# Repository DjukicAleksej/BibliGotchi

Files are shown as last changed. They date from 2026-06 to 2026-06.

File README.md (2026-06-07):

<div align="center">

# 🎮 BibliGotchi

<p align="center" style="font-size: 1.1em; max-width: 800px; line-height: 1.6;">
  A custom-made Tamagotchi with a heavenly touch. Made by a 17-year-old from Bosnia and Herzegovina, this project showcases my learning journey in the hardware ecosystem. I designed this using KiCad for the PCB, OnShape for the structural case, and the Arduino IDE for the firmware.
</p>

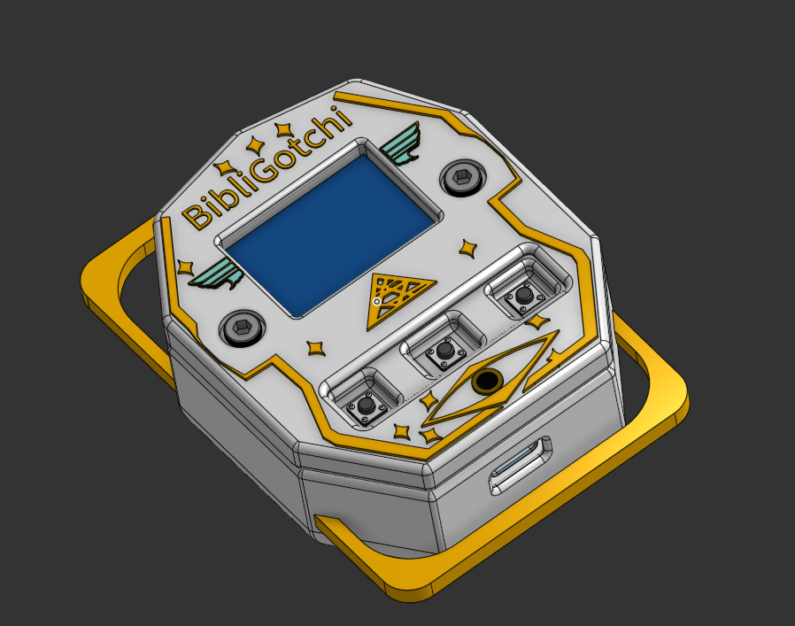
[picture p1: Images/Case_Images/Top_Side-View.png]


<p align="center" style="max-width: 800px; line-height: 1.6;">
  This Tamagotchi features 3 main tracking stats: <strong>Hunger</strong>, <strong>Energy</strong>, and <strong>Happiness</strong>. You can improve these parameters by physically interacting with the device using tactile buttons—each mapped to mapped behaviors like playing, feeding, or sleeping. Depending on active stats, 4 distinct screen expressions dynamically cycle: neutral, happy, sad, or sleeping. All 32x32 pixel sprites are custom-drawn, giving you the template to easily drop in your own custom artwork!
</p>

## 💡 Why Did I Build This?

<p align="center" style="max-width: 800px; line-height: 1.6;">
  I built this project to qualify for <strong>Fallout</strong>, a hardware hackathon organized by the non-profit community <strong>Hack Club</strong>. I gravitated toward building a Tamagotchi because it sits at the perfect crossroads: complex enough to challenge my design skills, yet interactive enough to stand out. In a world saturated with purely web-based apps, having a tangible, physical device makes it uniquely engaging. Through this process, I significantly deepened my understanding of firmware architecture and structural enclosure engineering.
</p>

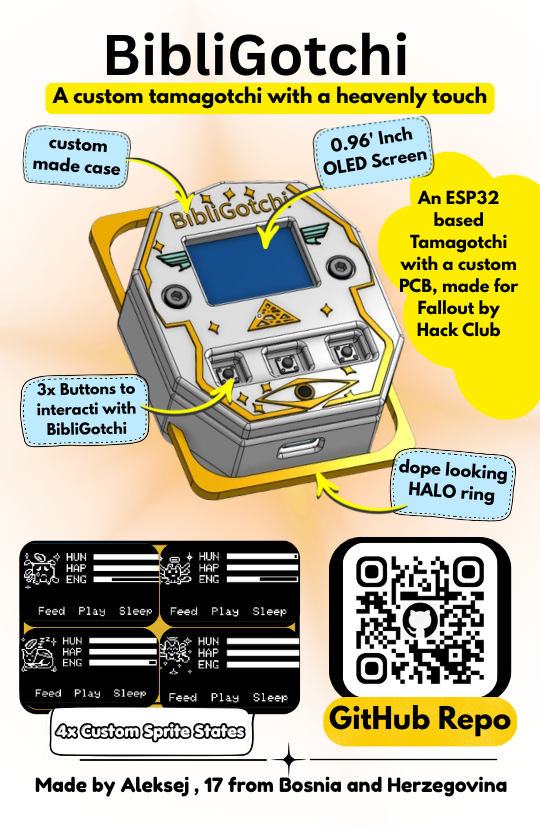
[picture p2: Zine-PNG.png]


---

<p align="center">
  <a href="Zine.pdf">📖 Read the Zine</a>
  &nbsp;&nbsp;•&nbsp;&nbsp;
  <a href="PCB-Files/Gerbers.zip">📦 Download Gerbers</a>
  &nbsp;&nbsp;•&nbsp;&nbsp;
  <a href="Case-Files/">📐 STEP Case Files</a>
  &nbsp;&nbsp;•&nbsp;&nbsp;
  <a href="BOM/BOM.csv">🧾 PCB BOM</a>
</p>

---

</div>

## 🔍 Overview
BibliGotchi is built around the **Seeed Studio XIAO ESP32-C3**, utilizing a custom PCB routed in KiCad to interface all peripherals smoothly. 

### Key Features:
* **Display**: 0.96" OLED screen for crisp UI rendering.
* **Power**: Integrated 3.7V 500mAh lithium-polymer battery.
* **Audio & Input**: Passive buzzer for alerts alongside 3 interactive navigation switches.
* **Enclosure**: Modeled inside OnShape ([View OnShape CAD Here](https://cad.onshape.com/documents/44d918d4bf107306610f1545/w/f7f086a823beff1369bb4e84/e/70df229ea8fe1c8cd39e3565)). Features filleted edge-geometry to completely eliminate sharp surfaces, precise cutouts for the USB-C port, and an internal structural sub-enclosure. The battery is safely clamped using a dual-screw retention bracket.
* **Firmware**: Written in C++ targeting the Arduino runtime environment. It implements real-time lifecycle status loops (tracking age, happiness levels, and depletion intervals) rendered via custom graphical progress bars.

---

## 📐 Case Gallery

| Top View | Top Side View |
| :---: | :---: |
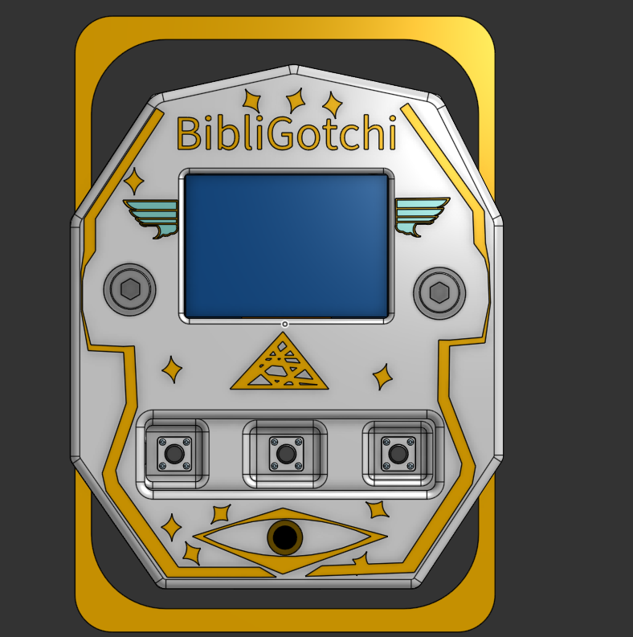
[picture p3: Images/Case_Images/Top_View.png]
Normal case view
|  | Top side-view |
| **Bottom View** | **Exploded View** |
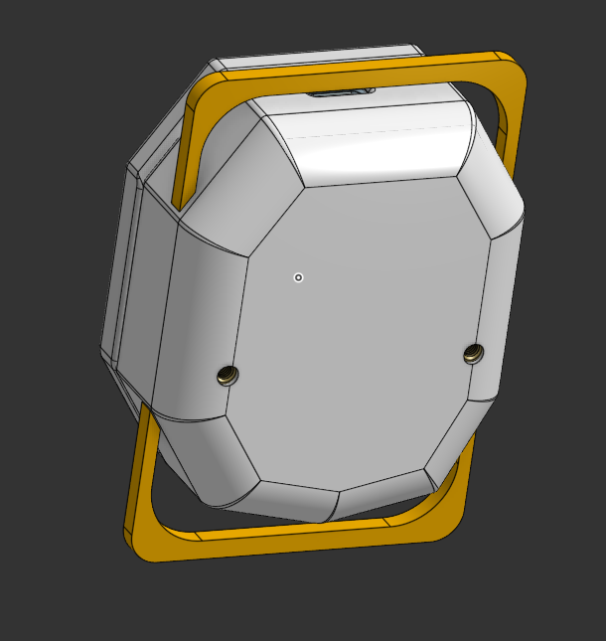
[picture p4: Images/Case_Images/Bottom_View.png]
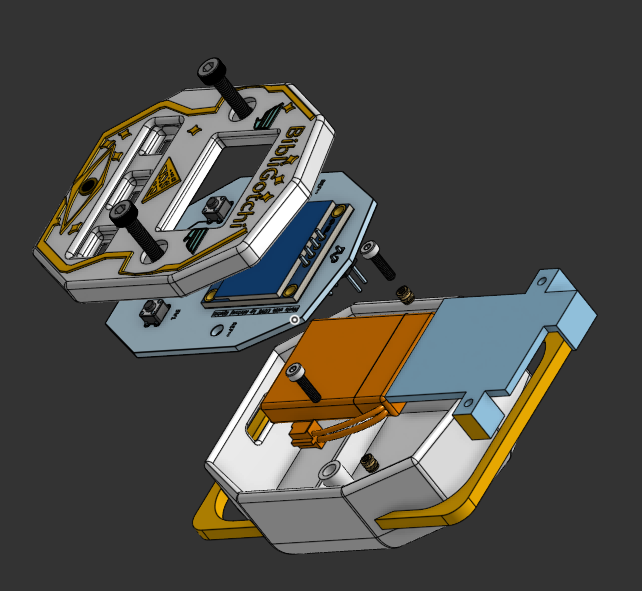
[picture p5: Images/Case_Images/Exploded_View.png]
|  |  |

---

## ⚡ PCB Gallery

| Top View 1 | Top View 2 |
| :---: | :---: |
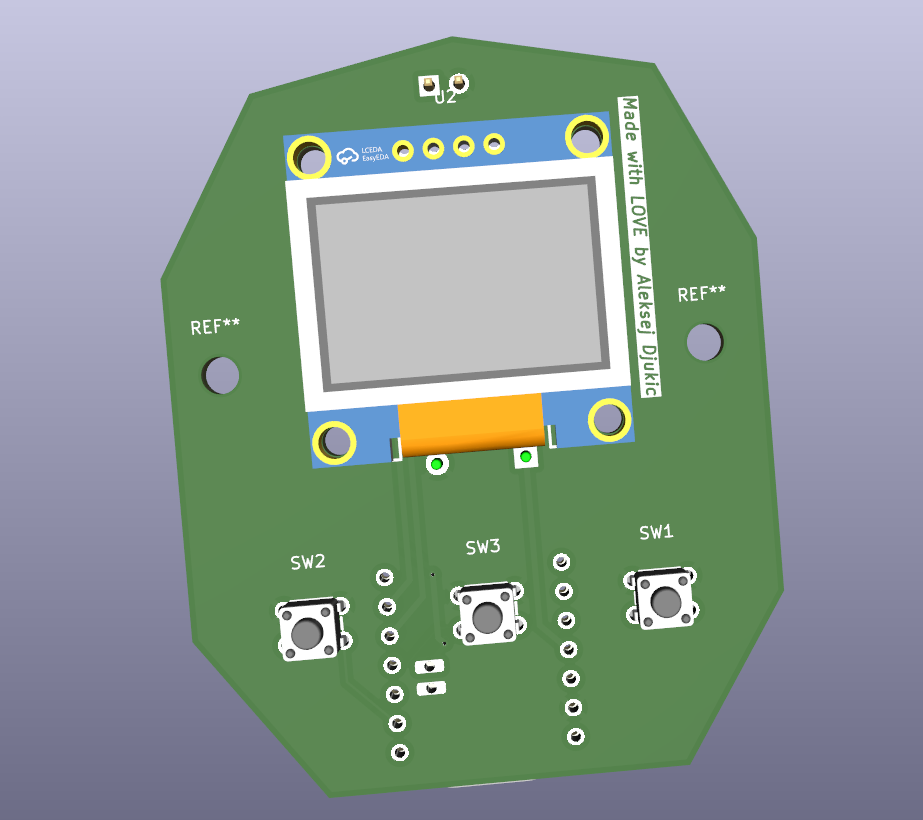
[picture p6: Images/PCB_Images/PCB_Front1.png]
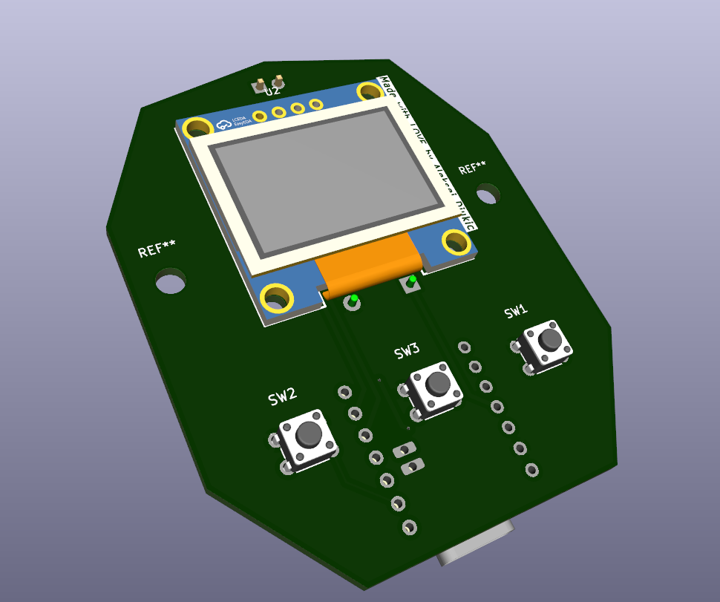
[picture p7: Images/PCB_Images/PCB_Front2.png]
|  |  |
| **Bottom View 1** | **Bottom View 2** |
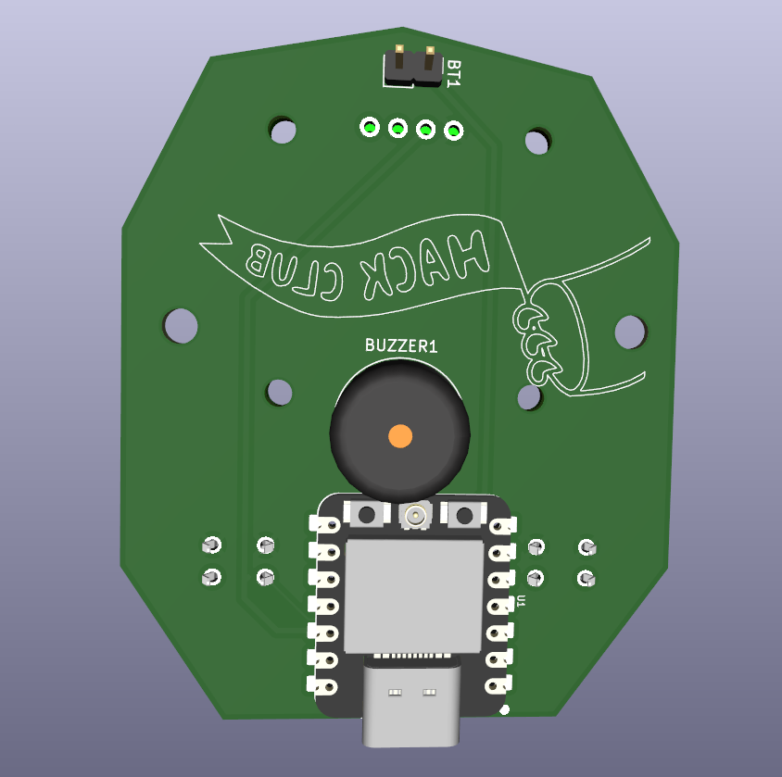
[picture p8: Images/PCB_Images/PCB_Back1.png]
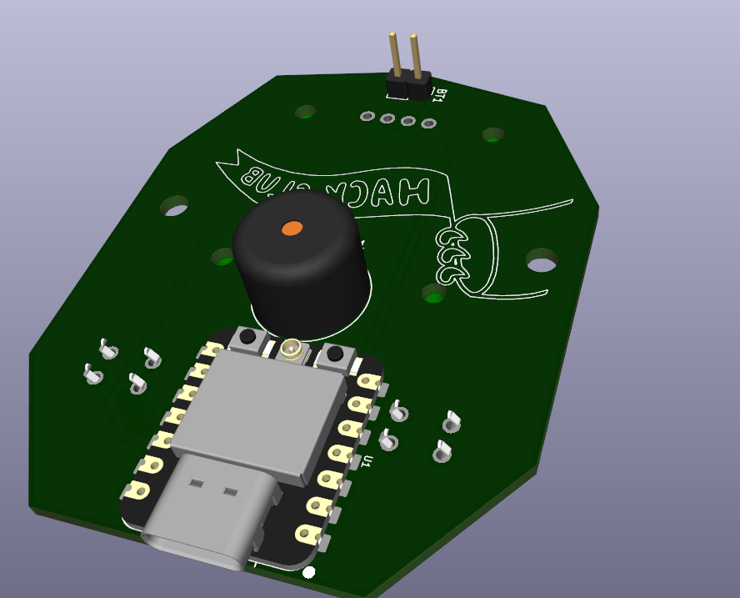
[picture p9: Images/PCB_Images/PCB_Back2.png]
|  |  |

### Schematic

<p align="center">
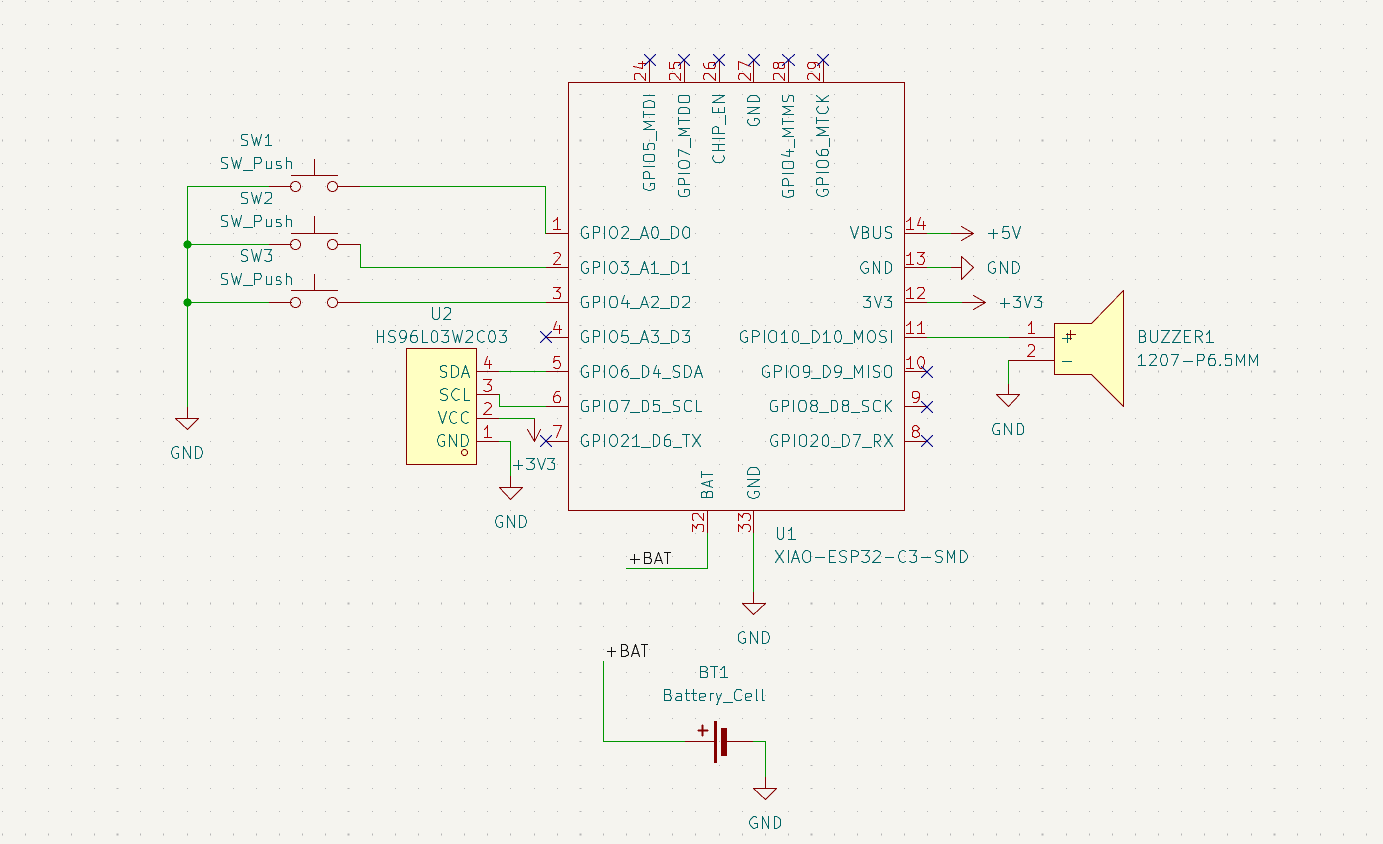
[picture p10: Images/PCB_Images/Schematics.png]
USB hub schematic
  
</p>
---

## 🗺️ Trace Routing

| Top Routing Layer | Bottom Routing Layer |
| :---: | :---: |
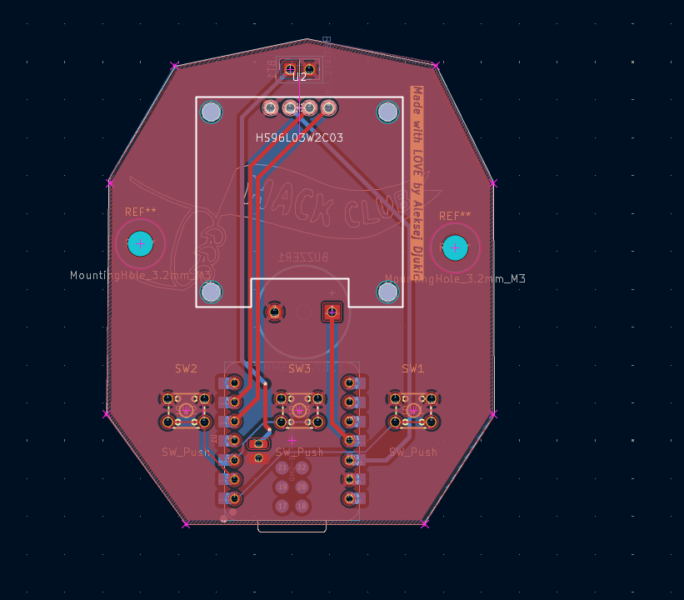
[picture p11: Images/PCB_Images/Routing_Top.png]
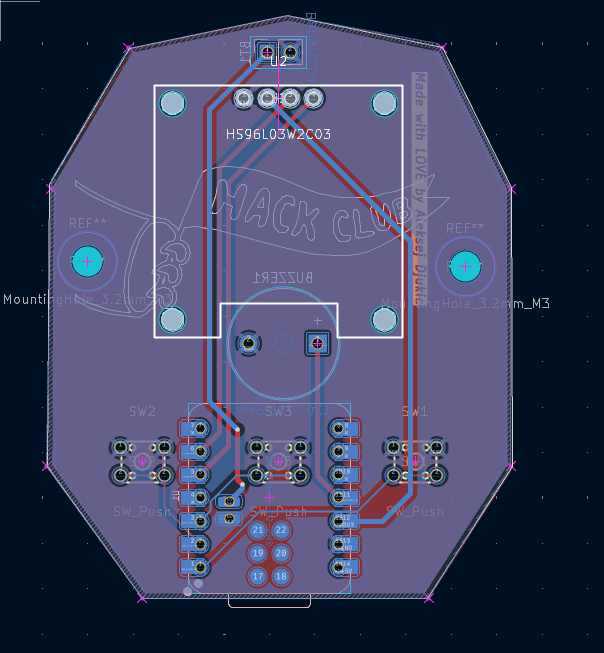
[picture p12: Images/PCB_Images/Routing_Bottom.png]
|  |  |

---

### 🛠️ Bill of Materials (BOM)

| Item | Description | Value | LCSC Part | Qty | MOQ | Unit Price | Total Price | Resources |
| :--- | :--- | :--- | :--- | :---: | :---: | :---: | :---: | :--- |
| Battery | Single-cell battery | Battery_Cell | | 1 | 1 | $5.11 | $5.11 | [Datasheet](https://www.kiwi-electronics.com/image/catalog/pdf/LP503035%20500mAh%203.7V%20%28AD306053%29%2020230615%5B34%5D.pdf), [Purchase Link](https://www.aliexpress.com/item/1005006043243361.html) |
| Buzzer | Passive Buzzer | 1207-P6.5MM | C49246964 | 1 | 10 | $0.03 | $0.32 | [Datasheet](https://www.lcsc.com/datasheet/C49246964.pdf), [Purchase Link](https://www.lcsc.com/product-detail/C49246964.html) |
| Switch | Push button switch, generic, two pins | SW_Push | C2888493 | 3 | 50 | $0.01 | $0.54 | [Datasheet](https://www.lcsc.com/datasheet/C2888493.pdf), [Purchase Link](https://www.lcsc.com/product-detail/C2888493.html) |
| ESP32-C3 MCU | IoT mini development board | XIAO-ESP32-C3-SMD | | 1 | 1 | $5.67 | $5.67 | [Datasheet](https://files.seeedstudio.com/wiki/XIAO_WiFi/Resources/esp32-c3_datasheet.pdf), [Purchase Link](https://www.aliexpress.com/item/1005006979844970.html) |
| OLED Display | 0.96" Inch OLED Display | HS96L03W2C03 | C5248080 | 1 | 1 | $2.24 | $2.24 | [Datasheet](https://www.lcsc.com/datasheet/C5248080.pdf), [Purchase Link](https://www.lcsc.com/product-detail/C5248080.html) |
| PCB | Hardware Fabrication Support | - | - | 1 | 5 | - | $4.00 | - |
| PCB Shipping | Shipping for the PCB, its kinda expensive cause I live outside the EU | - | - | - | - | - | $26.00 | - |
| **Total** | | | | **8** | **68** | **$13.10** | **$43.88** | |

### ⚙️ Structural Fasteners (Build BOM)

| Item | Description | Quantity | Total Price |
| :--- | :--- | :---: | :--- |
| M3 L20 Screws | Connects the structural Bottom and Top case layers while mounting the internal PCB safely | 2 | $0.10 
| M2 Screws L8mm | Shorter structural screws allocated to tighten down the custom internal battery clamp | 2 | $0.10 
| M3 Heat Set Inserts | Threaded brass inserts allowing permanent, secure fastening profiles for outer casing | 2 | $0.10 
| M2 Heat Set Inserts | High-precision brass inserts matching structural point stabilization requirements | 2 | $0.20 
| **Total** | | **12** | **$0.60** |

---

## 🔧 Case Assembly Tutorial

### Step 1: Putting in the Battery
Seat the Battery into its enclosure in the Bottom Part, then put heat set inserts into the Battery Holder and place it onto the Battery Enclosure and screw it in.

| Align the Battery | Secure it with the Battery Holder |
| :---: | :---: |
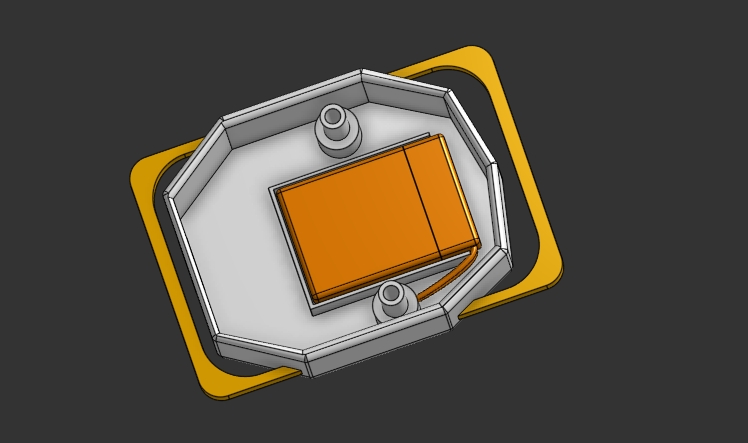
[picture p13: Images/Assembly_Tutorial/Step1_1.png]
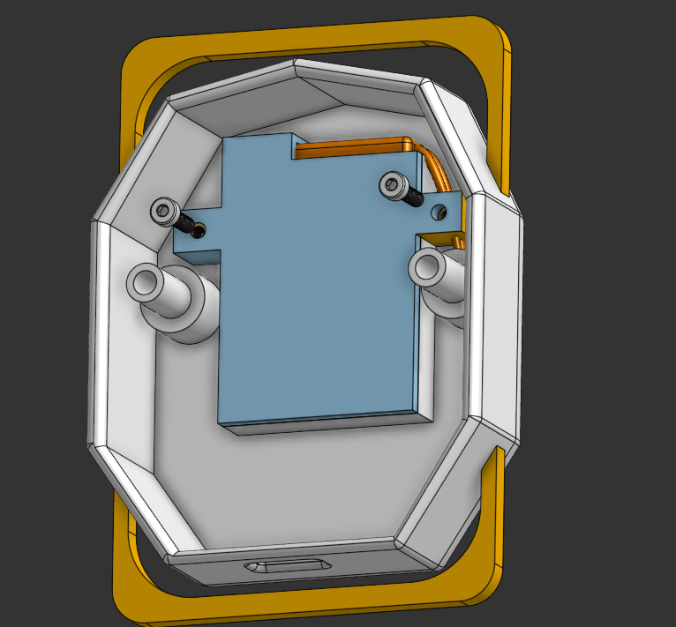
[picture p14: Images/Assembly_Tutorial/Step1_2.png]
|  |  |

### Step 2: Assembling the PCB and the Top Cover to the Bottom Part
Press-fit the M3 brass heat-set inserts straight into the designated holes inside the lower structural wall. Bring the PCB to align its mounting holes with the supports from the Bottom Part, and then Align the Top Cover so that you can screw in the top cover and bottom cover through the hole nicely,  and drive the M3 L20 screws downward to securely clamp the whole sandwich layer together.

| Put in the M3 heat set inserts | Align the PCB | Put the Top Cover Nicely aligned on the PCB |
| :--: | :---: | :---: |
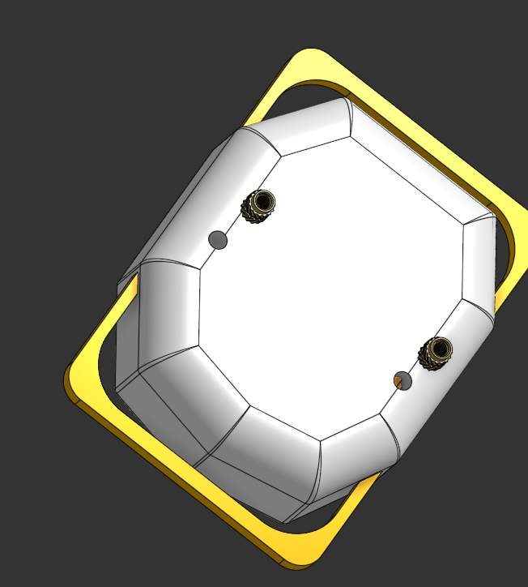
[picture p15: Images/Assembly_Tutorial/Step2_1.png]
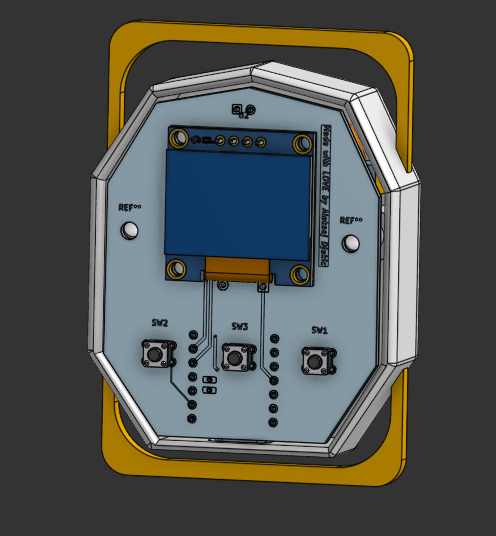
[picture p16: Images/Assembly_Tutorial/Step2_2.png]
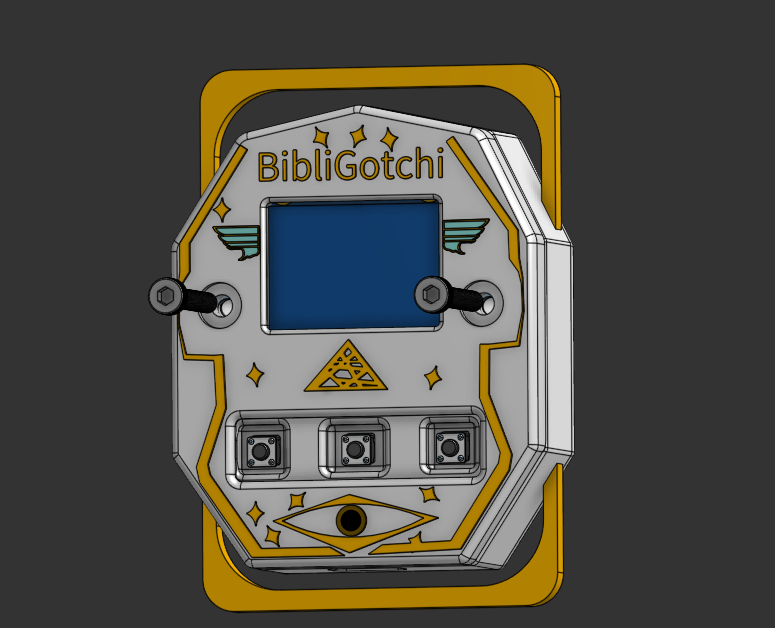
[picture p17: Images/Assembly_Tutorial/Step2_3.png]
|  |  |   |

---

## 💻 Firmware Setup

The runtime firmware is engineered inside the Arduino core using C++. It executes cyclic ticks tracking core stat logic while parsing interactive structural button state triggers via hardware pull-up inputs:
* **Left Button (`Feed`)**: Replenishes missing core **HUN (Hunger)** values, keeping your pet fed.
* **Middle Button (`Play`)**: Trades **-5 ENG (Energy)** to buy **+10 HAP (Happiness)** metrics.
* **Right Button (`Sleep`)**: Switches state vectors directly into the deep sleeping routine, generating a custom visual screen profile and recharging **+15 ENG (Energy)** metrics.

### Expressive Character Matrix

| Sad State (`Any Stat < 30`) | Happy State (`All Stats > 50`) |
| :---: | :---: |
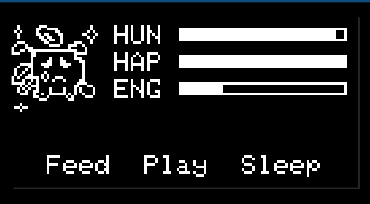
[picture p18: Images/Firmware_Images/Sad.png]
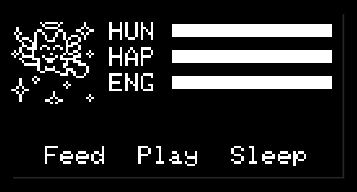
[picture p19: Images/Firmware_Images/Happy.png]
|  |  |
| **Neutral State (`Standard Default`)** | **Sleep State (`Sleep Trigger Engaged`)** |
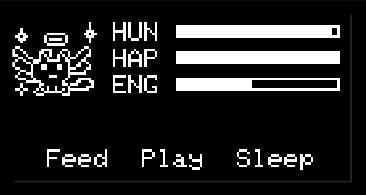
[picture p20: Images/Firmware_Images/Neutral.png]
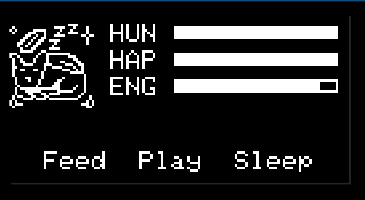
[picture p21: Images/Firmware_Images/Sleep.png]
|  |  |

---

### 🚀 Compilation & Flashing Instructions

### Step 1: Install the ESP32 Board Package URL
Because ESP32 variants require platform abstraction extensions, add the official Espressif core indexes inside your environment parameters:
1. Open the **Arduino IDE**.
2. Navigate to **File** > **Preferences** (macOS: **Arduino IDE** > **Settings**).
3. Append the following address into the **Additional Boards Manager URLs** input row:
   `https://espressif.github.io/arduino-esp32/package_esp32_index.json`
   *(Note: Separate multiple indices using standard commas if you have existing entries).*
4. Click **OK** and allow indexing to finalize.

### Step 2: Fetch the Core Toolkit
1. Enter the Board Repository panel via **Tools** > **Board** > **Boards Manager**.
2. Run an evaluation sweep searching for `esp32`.
3. Locate **esp32 by Espressif Systems** and click **Install**. 
   *(Important: Verify package versions display `3.0.0` or newer to guarantee complete ESP32-C3 controller support).*

### Step 3: Instantiate local Sketch Files
Create a fresh runtime workspace profile inside the environment via **File** > **New Sketch**. Save this locally on your machine.

### Step 4: Bind Target Hardware Options
1. Go to **Tools** > **Board** > **esp32**.
2. Choose your precise module footprint: **XIAO ESP32C3**.
3. Select your system hardware serial mount path line entry under **Tools** > **Port**.

### Step 5: Resolve Peripheral Libraries
Enter the library workspace panel through **Sketch** > **Include Library** > **Manage Libraries** and search for and fetch the following dependencies:
1. **Adafruit SSD1306** (by Adafruit)
2. **Adafruit GFX Library** (by Adafruit—accept any cascading tracking dependencies if prompted)

### Step 6: Deploy Flash Assets
Link your BibliGotchi assembly to your development machine using a dependable data-rated USB-C cord. Copy the logic content found within your local `BibliGotchi_Firmware.ino` file directly over to your primary IDE sketch pane.
1. Click the **Verify** icon (the top-left checkmark layout symbol) to check for structural code errors.
2. Hit the **Upload** arrow icon situated immediately alongside it to build and flash the image over onto the controller.

### Step 7: Enjoy! 🎉
With both structural chassis parameters and software components fully synchronized, your interactive BibliGotchi buddy is officially up and running!

---

<div align="center">

Built with ❤️ by Aleksej Djukic

**BibliGotchi • Fallout 2026**

</div>

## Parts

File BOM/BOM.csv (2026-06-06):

Item | Description | Value | Datasheet | LCSC Part | Link | Qty | MOQ | Unit Price | Total Price
Battery | Single-cell battery | Battery_Cell | https://www.kiwi-electronics.com/image/catalog/pdf/LP503035%20500mAh%203.7V%20%28AD306053%29%2020230615%5B34%5D.pdf | - | https://www.aliexpress.com/item/1005006043243361.html | 1 | 1 | $5.11 | $5.11
Buzzer | Passive Buzzer | 1207-P6.5MM | https://www.lcsc.com/datasheet/C49246964.pdf | C49246964 | https://www.lcsc.com/product-detail/C49246964.html | 1 | 10 | $0.03 | $0.32
Switch | Push button switch, generic, two pins | SW_Push | https://www.lcsc.com/datasheet/C2888493.pdf | C2888493 | https://www.lcsc.com/product-detail/C2888493.html | 3 | 50 | $0.01 | $0.54
ESP32-C3 MCU | IoT mini development board | XIAO-ESP32-C3-SMD | https://files.seeedstudio.com/wiki/XIAO_WiFi/Resources/esp32-c3_datasheet.pdf | - | https://www.aliexpress.com/item/1005006979844970.html | 1 | 1 | $5.67 | $5.67
OLED Display | 0.96 Inch OLED Display | HS96L03W2C03 | https://www.lcsc.com/datasheet/C5248080.pdf | C5248080 | https://www.lcsc.com/product-detail/C5248080.html | 1 | 1 | $2.24 | $2.24
PCB | PCB fabrication using JLCPCB | - | - | - | - | 1 | 5 | - | $4.00
PCB Shipping | Shipping to a country outside EU so it's expensive | - | - | - | - | 1 | 1 | - | $26.00
Total | - | - | - | - | - | 8 | 68 | $13.10 | $43.88

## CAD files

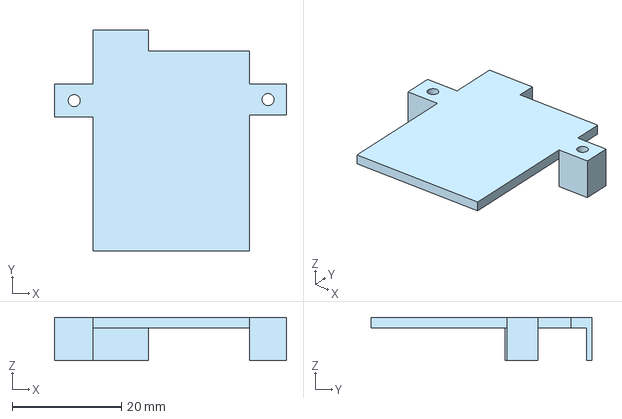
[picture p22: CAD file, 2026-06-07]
Case-Files/BibliGotchi Case - Battery Holder.step
42.4 x 40.3 x 7.92 mm

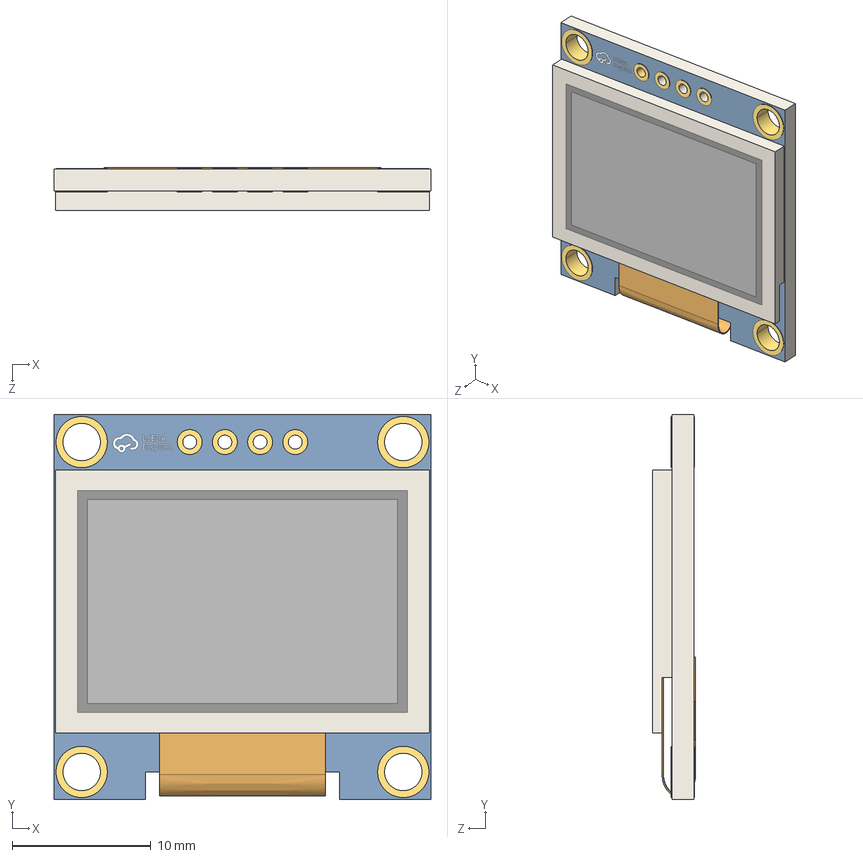
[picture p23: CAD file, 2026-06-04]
PCB-Files/Extra Imports/3D_Model_Imports/OLED-TH_L27.8-W27.2-P2.54_C9900033791.step
27.2 x 27.8 x 3.12 mm

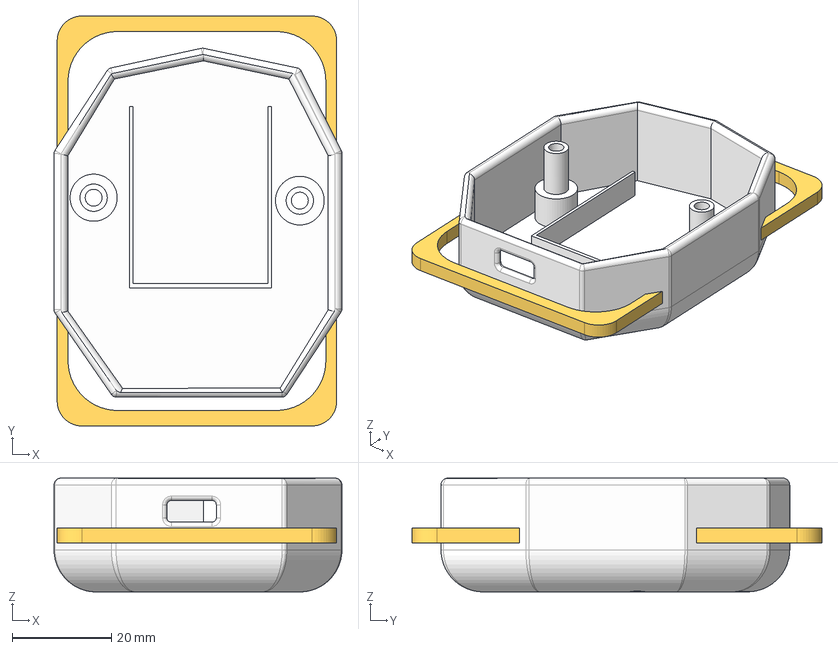
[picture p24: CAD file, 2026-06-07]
Case-Files/BibliGotchi Case - Bottom Case.step
57.9 x 82.5 x 22.9 mm

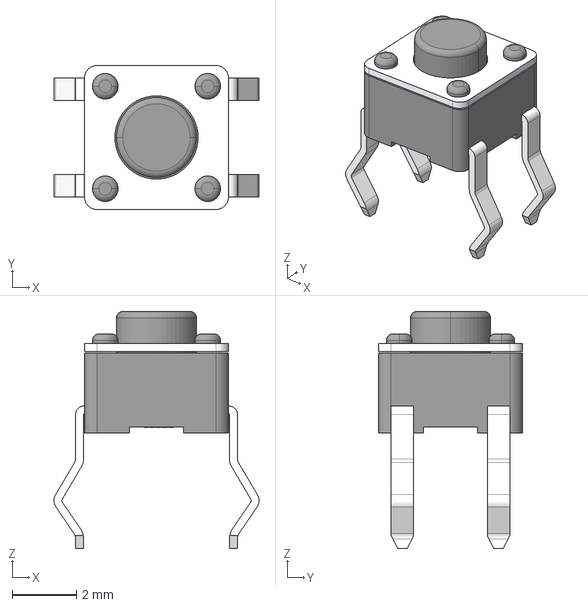
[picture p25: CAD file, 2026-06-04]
PCB-Files/Extra Imports/3D_Model_Imports/SW-TH_4P-L4.5-W4.5-P3.00-LS4.8.step
6.40 x 4.50 x 7.40 mm

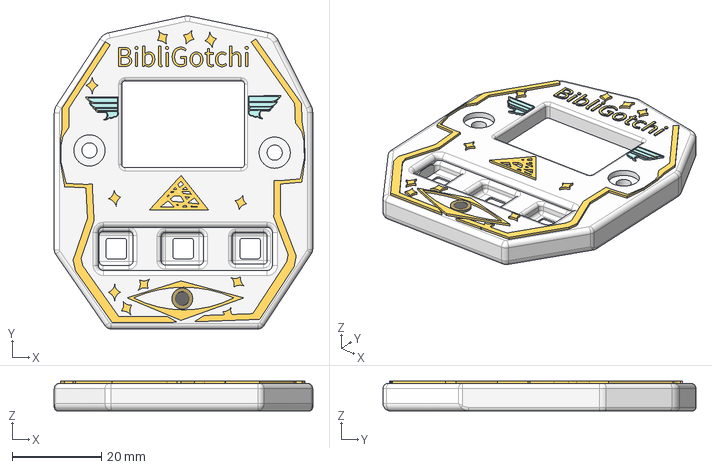
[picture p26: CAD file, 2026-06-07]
Case-Files/BibliGotchi Case - Top Cover.step
57.9 x 70.1 x 6.70 mm

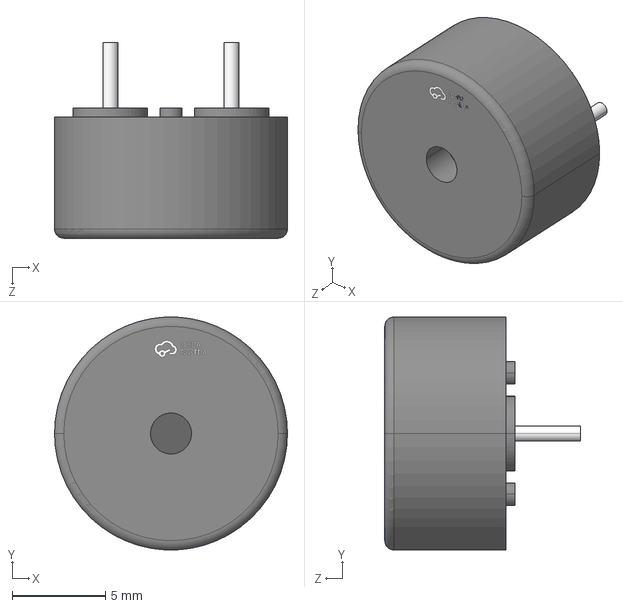
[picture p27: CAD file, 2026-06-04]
PCB-Files/Extra Imports/3D_Model_Imports/BUZ-TH_BD12.5-H7.0-P6.5.step
12.5 x 12.5 x 10.5 mm

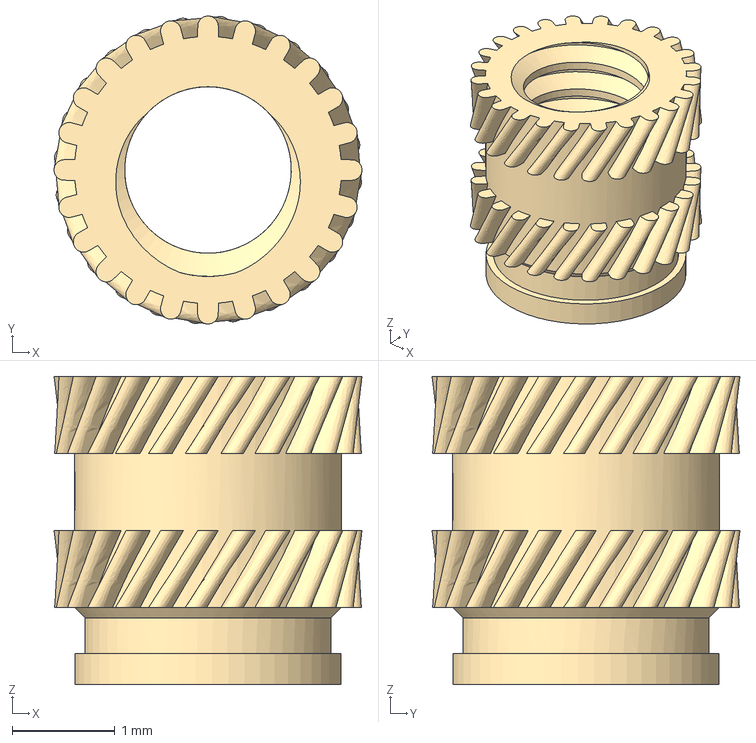
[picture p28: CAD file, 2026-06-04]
Case-Files/Components-and-Screws-3D-Models/Heat Set M2 Insert.step
3.00 x 3.00 x 3.00 mm

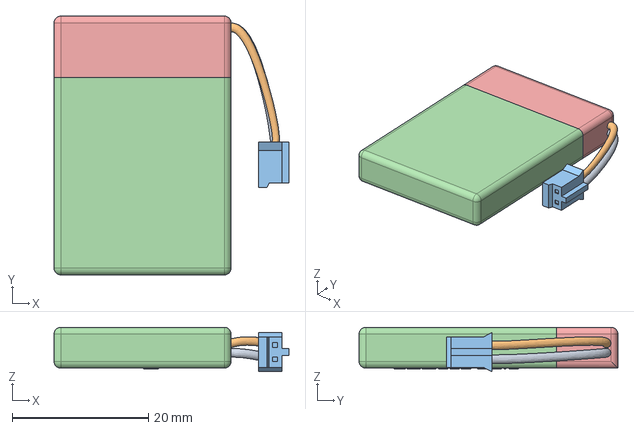
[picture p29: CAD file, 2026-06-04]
Case-Files/Components-and-Screws-3D-Models/Battery.step
34.5 x 38.0 x 6.52 mm

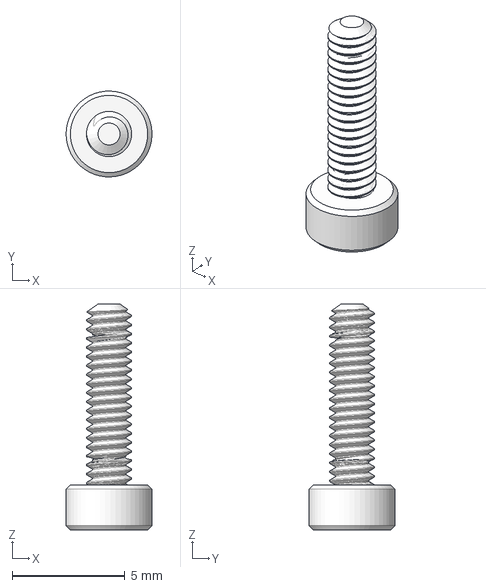
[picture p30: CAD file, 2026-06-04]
Case-Files/Components-and-Screws-3D-Models/M2_L8_Screw.step
3.80 x 3.80 x 10.00 mm

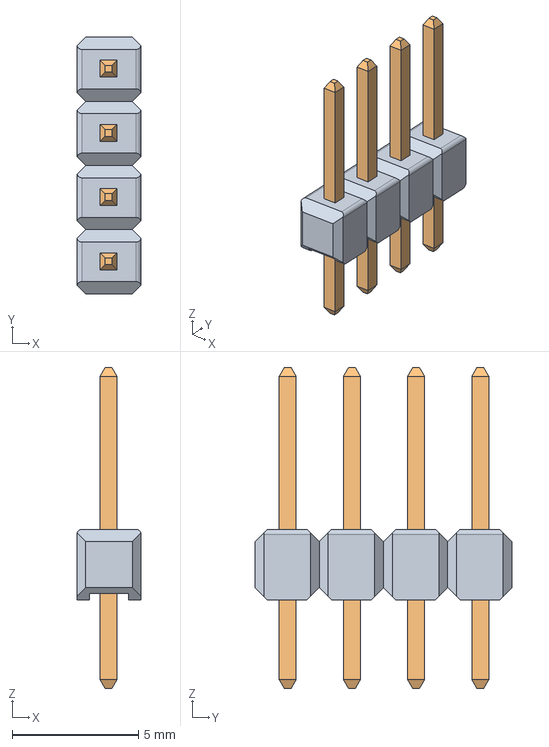
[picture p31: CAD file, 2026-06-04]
Case-Files/Components-and-Screws-3D-Models/1x4 TH Pitch 2_54mm.step
2.54 x 10.2 x 12.7 mm

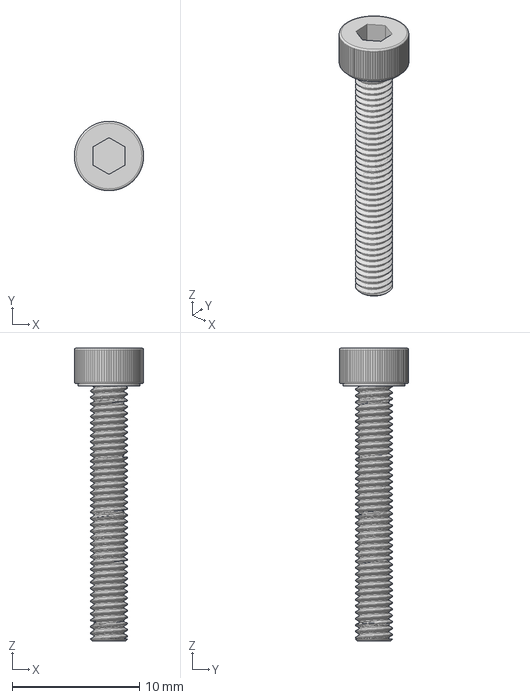
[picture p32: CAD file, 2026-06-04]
Case-Files/Components-and-Screws-3D-Models/M3_L20_Screw.step
5.45 x 5.45 x 23.0 mm

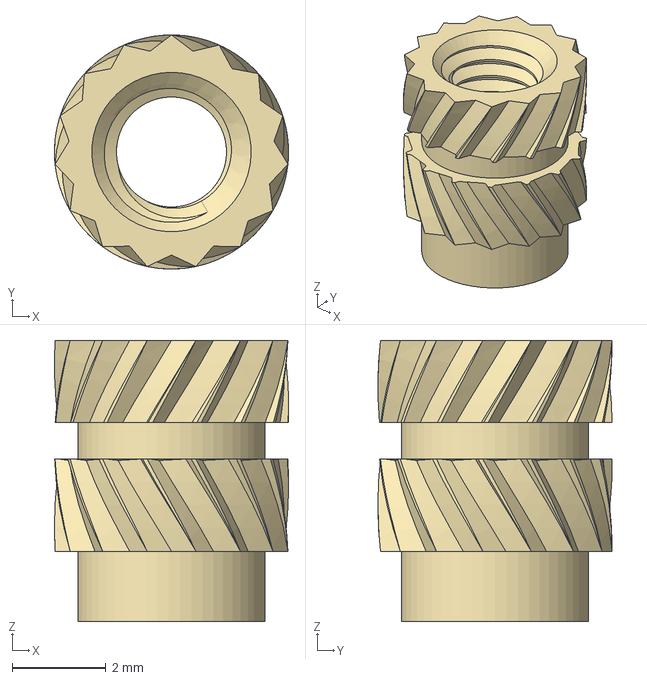
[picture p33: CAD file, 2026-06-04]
Case-Files/Components-and-Screws-3D-Models/Heat Set M3 Insert.step
5.00 x 5.00 x 6.00 mm

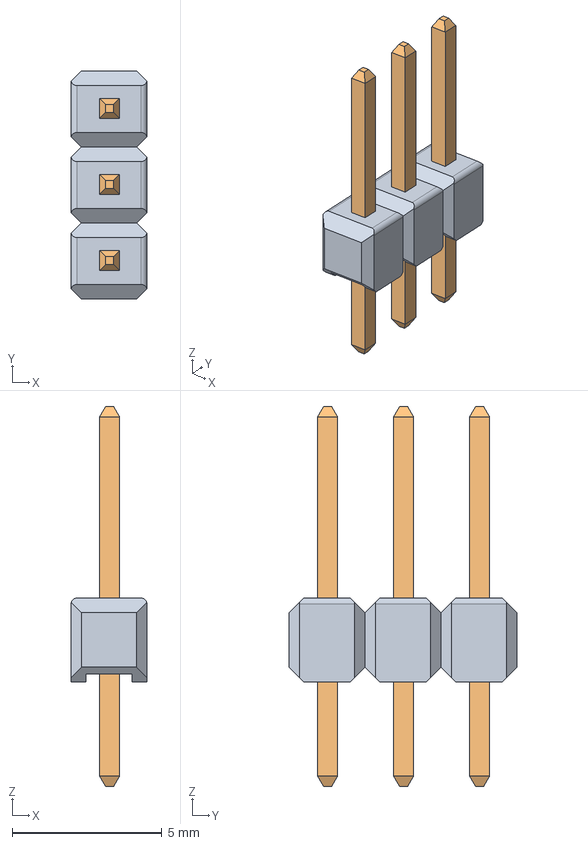
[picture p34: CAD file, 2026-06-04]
Case-Files/Components-and-Screws-3D-Models/1x3_TH Pitch 2_54mm.step
2.54 x 7.62 x 12.7 mm

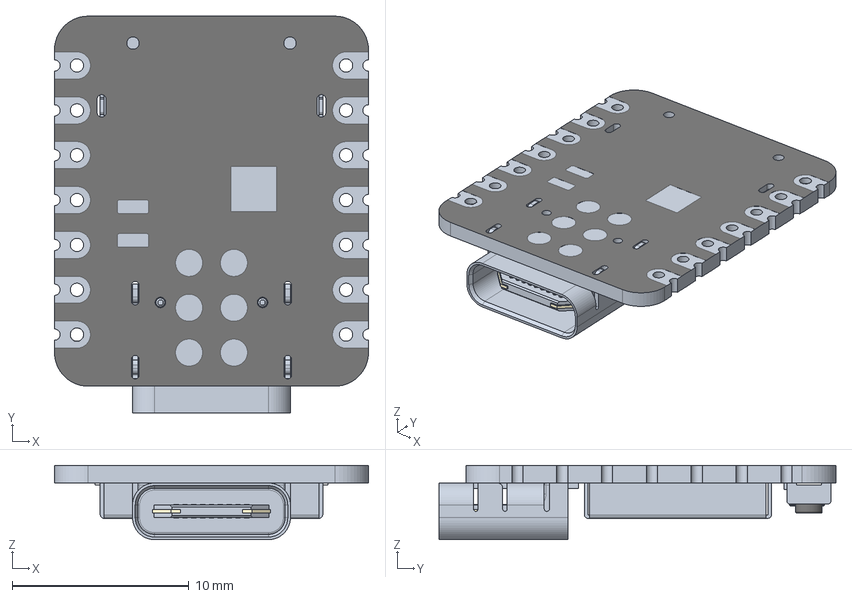
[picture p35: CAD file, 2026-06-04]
Case-Files/Components-and-Screws-3D-Models/XIAO-ESP32-C3.step
17.8 x 22.5 x 4.21 mm

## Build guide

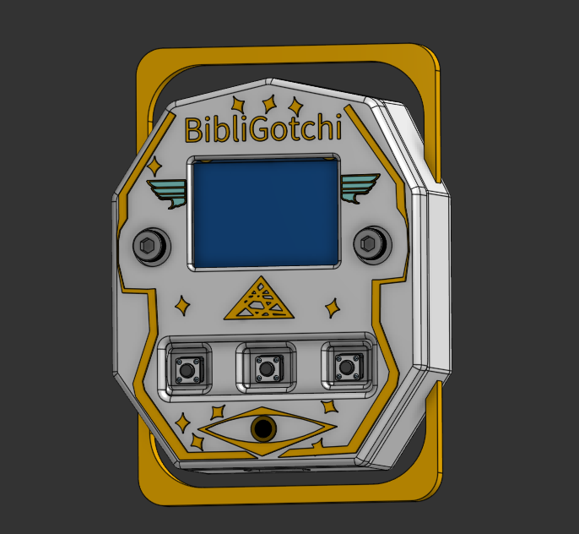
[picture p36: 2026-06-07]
Images/Assembly_Tutorial/Finished.png

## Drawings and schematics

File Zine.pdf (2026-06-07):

# BibliGotchi

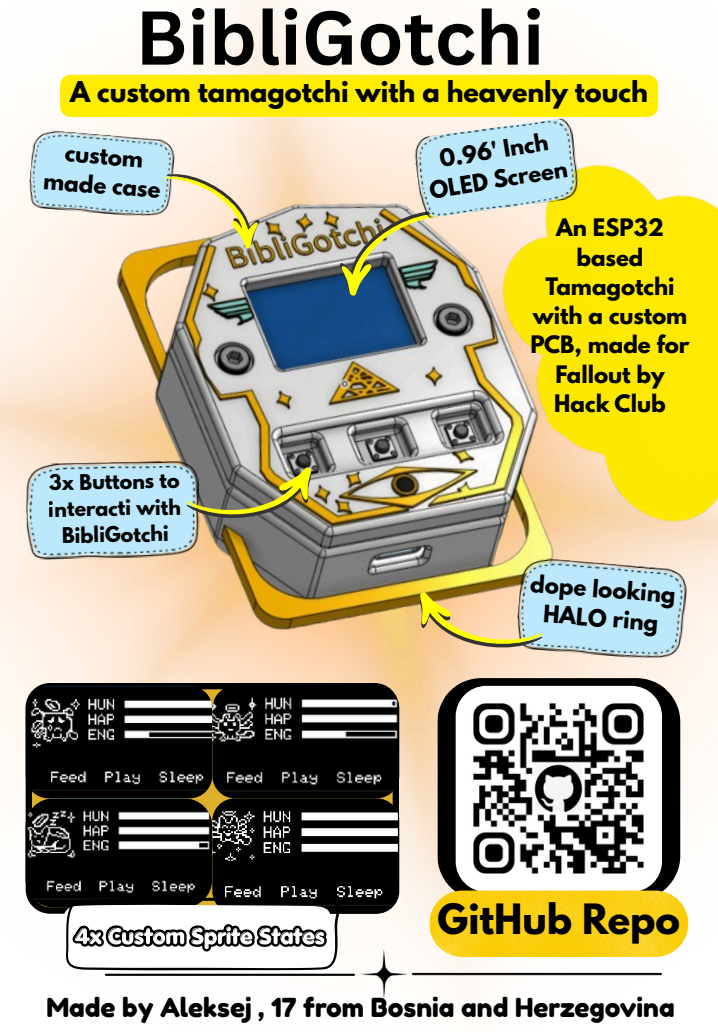
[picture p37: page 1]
3x Buttons to interacti with BibliGotchi; dope looking HALO ring; 44xx CCuussttoomm SSpprriittee SSttaatteess; GitHub Repo; custom made case; 0.96' Inch OLED Screen

A custom tamagotchi with a heavenly touch

An ESP32
based
Tamagotchi
with a custom
PCB, made for
Fallout by
Hack Club

Made by Aleksej , 17 from Bosnia and Herzegovina

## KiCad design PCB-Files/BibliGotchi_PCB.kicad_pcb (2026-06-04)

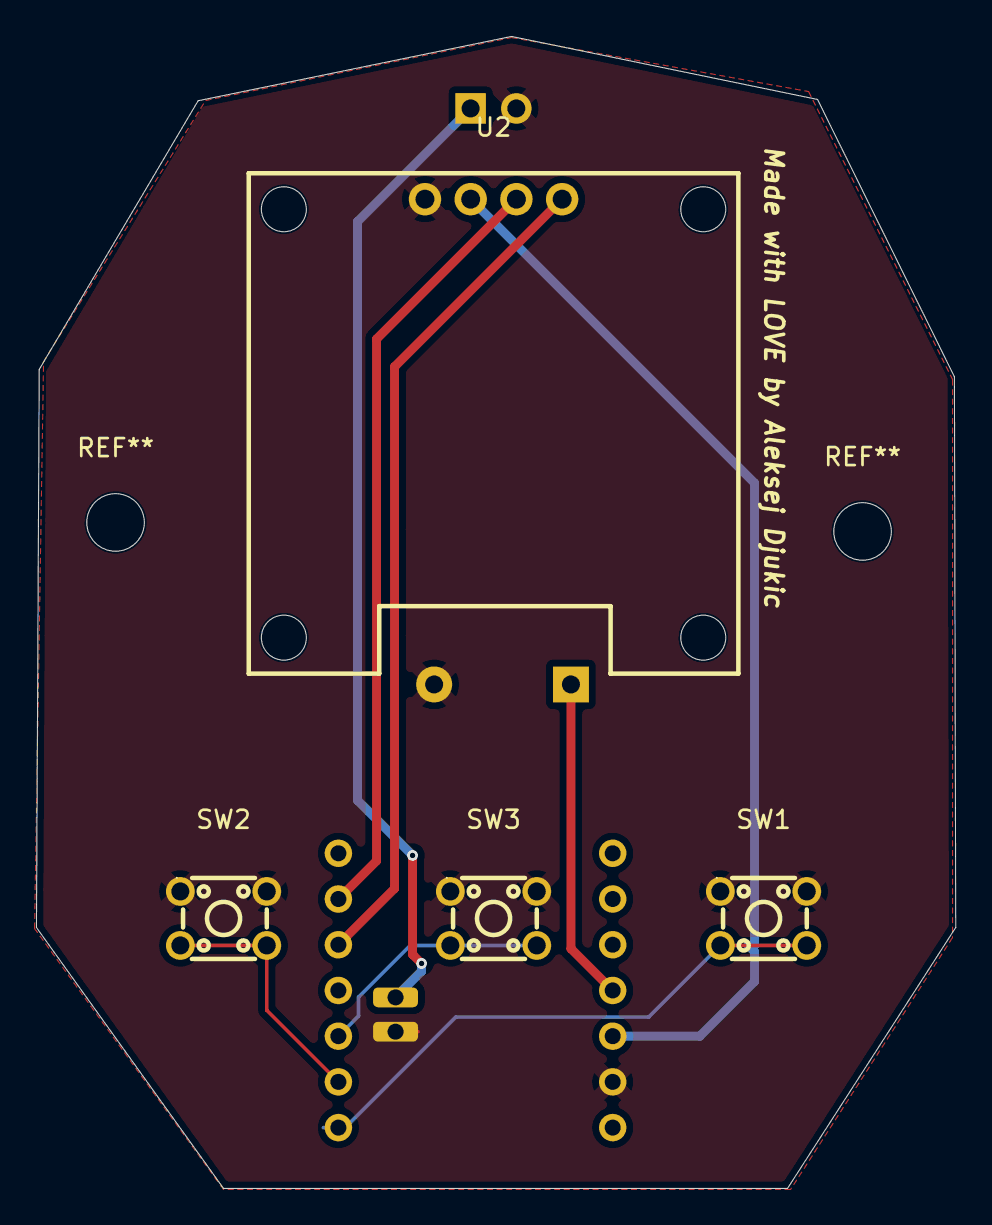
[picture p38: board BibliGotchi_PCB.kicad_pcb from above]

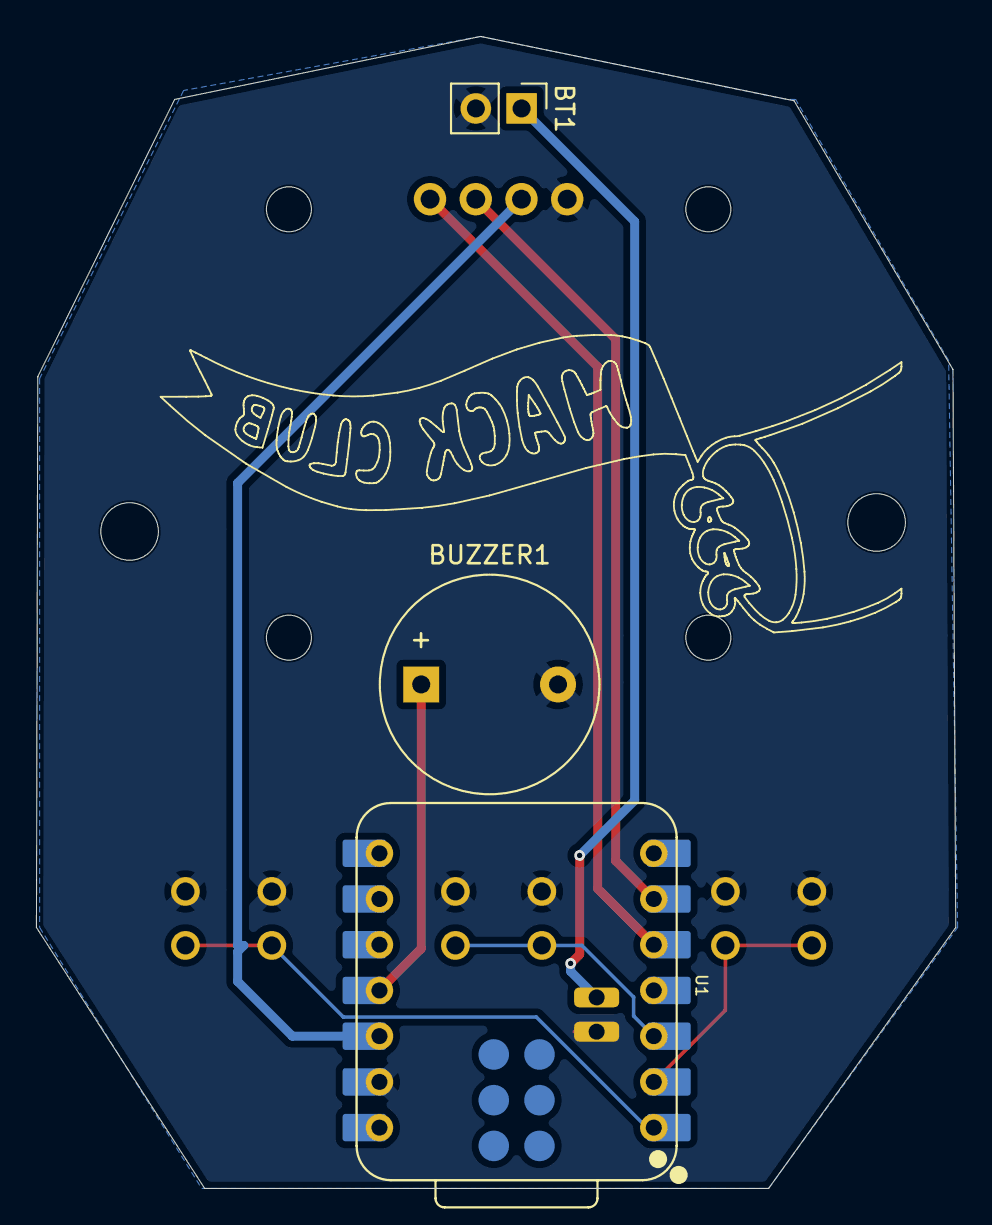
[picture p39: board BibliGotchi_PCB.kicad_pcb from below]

Board: 2 copper layers, 51.1 x 64.0 mm, 7 parts (3 on the bottom side), 9 nets.

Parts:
BT1: Battery_Cell; PinHeader_1x02_P2.54mm_Vertical
BUZZER1: 1207-P6.5MM; Buzzer_12x9.5RM7.6
SW1, SW2, SW3: SW_Push; SW-TH_4P-L4.5-W4.5-P3.00-LS4.8
U1: XIAO-ESP32-C3-SMD; XIAO-ESP32-C3-DIP-SMD
U2: HS96L03W2C03; OLED-TH_L27.8-W27.2-P2.54_C9900033791

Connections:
+3V3: U1.12 (3V3), U2.2 (VCC)
/+BAT: BT1.1 (+), U1.15
GND: BT1.2 (-), BUZZER1.2 (-), SW1.1, SW2.1, SW3.1, U1.13 (GND), U1.16, U2.1 (GND)
unnamed: BUZZER1.1 (+), U1.11 (GPIO10_D10_MOSI)
unnamed: SW1.2, U1.1 (GPIO2_A0_D0)
unnamed: SW2.2, U1.2 (GPIO3_A1_D1)
unnamed: SW3.2, U1.3 (GPIO4_A2_D2)
unnamed: U1.5 (GPIO6_D4_SDA), U2.4 (SDA)
unnamed: U1.6 (GPIO7_D5_SCL), U2.3 (SCL)

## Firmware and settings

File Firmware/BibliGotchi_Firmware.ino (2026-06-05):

//Buttons (traced from the schematics)
#define BTN1 0
#define BTN2 1
#define BTN3 2

//I2C Oled (traced from the schematics)
#define SCL 23
#define SDA 22

//Buzzer (traced from the schematics)
#define BUZZER 18 

#include <Wire.h>
#include <Adafruit_GFX.h>
#include <Adafruit_SSD1306.h>

#define SCREEN_WIDTH 128
#define SCREEN_HEIGHT 64
#define OLED_RESET -1

Adafruit_SSD1306 display(SCREEN_WIDTH, SCREEN_HEIGHT, &Wire, OLED_RESET);

// Kept D-prefix pins as requested
#define BTN_LEFT    D1
#define BTN_MIDDLE  D2
#define BTN_RIGHT   D0
#define BUZZER_PIN  D10

struct Pet {
  int hunger;
  int happiness;
  int energy;
  unsigned long age;
};

Pet pet;

enum Screen {
  SCREEN_MAIN,
  SCREEN_FEED,
  SCREEN_PLAY,
  SCREEN_SLEEP,
};
Screen currentScreen = SCREEN_MAIN;

//UPDATE PET Function
unsigned long lastUpdate = 0;

void updatePet() {
  if (millis() - lastUpdate > 10000) {  // every 10 seconds
    
    // Fixed: Handle passive logic based on screen state
    if (currentScreen == SCREEN_SLEEP) {
      // Pet recovers energy over time while sleeping
      pet.energy += 15;
      if (pet.energy >= 100) {
        pet.energy = 100;
        currentScreen = SCREEN_MAIN; // Wakes up automatically when full!
      }
    } else {
      // Normal ticking down when awake
      pet.hunger--;
      pet.happiness--;
      pet.energy--;
    }

    if (pet.hunger < 0) pet.hunger = 0;
    if (pet.happiness < 0) pet.happiness = 0;
    if (pet.energy < 0) pet.energy = 0;

    pet.age += 10;
    lastUpdate = millis();
  }
}

//Button Press Function
unsigned long lastButtonPress = 0;

void checkButtons() {
  if (millis() - lastButtonPress < 200) return;  // debounce

  // Fixed: Pressing any button while sleeping wakes the pet up
  if (currentScreen == SCREEN_SLEEP) {
    if (digitalRead(BTN_LEFT) == LOW || digitalRead(BTN_MIDDLE) == LOW || digitalRead(BTN_RIGHT) == LOW) {
      currentScreen = SCREEN_MAIN;
      tone(BUZZER_PIN, 2000, 100); // Wake up tone
      lastButtonPress = millis();
      return;
    }
  }

  // Normal button routine when awake
  if (digitalRead(BTN_LEFT) == LOW) {
    currentScreen = SCREEN_FEED;
    tone(BUZZER_PIN, 3000, 50);
    lastButtonPress = millis();
  }
  else if (digitalRead(BTN_MIDDLE) == LOW) {
    currentScreen = SCREEN_PLAY;
    tone(BUZZER_PIN, 4000, 50);
    lastButtonPress = millis();
  }
  else if (digitalRead(BTN_RIGHT) == LOW) {
    currentScreen = SCREEN_SLEEP;
    tone(BUZZER_PIN, 3500, 50);
    lastButtonPress = millis();
  }
}

//Screen Logic
void handleScreenLogic() {
  switch(currentScreen) {
    case SCREEN_FEED:
      pet.hunger += 10;
      if (pet.hunger > 100) pet.hunger = 100;
      currentScreen = SCREEN_MAIN; // Direct return for immediate stat boost
      break;

    case SCREEN_PLAY:
      pet.happiness += 10;
      pet.energy -= 5;
      if (pet.happiness > 100) pet.happiness = 100;
      if (pet.energy < 0) pet.energy = 0;
      currentScreen = SCREEN_MAIN; // Direct return for immediate stat boost
      break;

    case SCREEN_SLEEP:
      // Fixed: Removed instant return to MAIN so the sleep state is persistent and visible
      break; 

    case SCREEN_MAIN:
      break; 
  }
}

//CHARACTER SPRITES DRAWINGS
//****************************************//

//NEUTRAL
const unsigned char PROGMEM petNeutral[] = {
  0b00000000, 0b00000000, 0b00000000, 0b00000100,
  0b00000000, 0b00000000, 0b00000000, 0b00000100,
  0b00010000, 0b00000000, 0b00000000, 0b00000100,
  0b00010000, 0b00000000, 0b00000000, 0b00001110,
  0b00111000, 0b00000111, 0b11110000, 0b00011011,
  0b01101100, 0b00001000, 0b00001000, 0b00001110,
  0b00111000, 0b00001011, 0b11101000, 0b00000100,
  0b00010000, 0b00001000, 0b00001000, 0b00000100,
  0b00000000, 0b00000111, 0b11110000, 0b00000000,
  0b01100000, 0b00000000, 0b00000000, 0b00011000,
  0b10010000, 0b00011110, 0b00011000, 0b00100100,
  0b10001000, 0b00110010, 0b00100100, 0b01000100,
  0b11000100, 0b00101010, 0b01010100, 0b10001100,
  0b00110011, 0b00100100, 0b01001011, 0b00010000,
  0b01001000, 0b11100111, 0b11001100, 0b00110000,
  0b10000110, 0b11000000, 0b00000100, 0b01001000,
  0b10000001, 0b00011000, 0b01100100, 0b11000100,
  0b01100001, 0b00011000, 0b01100111, 0b00001100,
  0b00011001, 0b00000000, 0b00000100, 0b00010000,
  0b00100111, 0b00000000, 0b00000111, 0b11110000,
  0b01000001, 0b00000011, 0b10000100, 0b00000000,
  0b00111000, 0b10000000, 0b00001000, 0b01111100,
  0b00000111, 0b11100000, 0b00010000, 0b11000110,
  0b00010000, 0b00110000, 0b00011011, 0b10000010,
  0b00010000, 0b00100100, 0b10000100, 0b00001110,
  0b01101100, 0b01010100, 0b10010111, 0b11111000,
  0b00010000, 0b10001111, 0b11100100, 0b00000000,
  0b00010000, 0b01110000, 0b00011100, 0b00000000,
  0b00000000, 0b00000000, 0b00000000, 0b00000000,
  0b00000000, 0b00000000, 0b00000000, 0b00000000,
  0b00000000, 0b00000000, 0b00000000, 0b00000000,
  0b00000000, 0b00000000, 0b00000000, 0b00000000
};

//SAD
const unsigned char PROGMEM petSad[] = {
  0b00100000, 0b00111000, 0b00000000, 0b00000100,
  0b00100000, 0b01100111, 0b10000000, 0b00000100,
  0b01010000, 0b01000000, 0b11000000, 0b00001010,
  0b00100000, 0b01101100, 0b01100000, 0b00110001,
  0b00100000, 0b00110110, 0b00100000, 0b00001010,
  0b00000000, 0b00011011, 0b00100000, 0b00000100,
  0b00111000, 0b00001100, 0b00100001, 0b11000100,
  0b01000100, 0b00000011, 0b11000111, 0b00100000,
  0b10000111, 0b00000000, 0b00000100, 0b00010000,
  0b10011011, 0b11111111, 0b11111111, 0b00010000,
  0b11100001, 0b10000000, 0b00000001, 0b11110000,
  0b00000001, 0b10000000, 0b00000001, 0b00000000,
  0b00000001, 0b00000010, 0b00100001, 0b11000000,
  0b00000001, 0b00000110, 0b00110000, 0b01100000,
  0b00011111, 0b00011110, 0b00111100, 0b00100000,
  0b00100011, 0b00001100, 0b00011000, 0b00100000,
  0b01000101, 0b00000000, 0b00000000, 0b00100000,
  0b01001001, 0b00001000, 0b00000000, 0b00100000,
  0b01010011, 0b00010100, 0b00000000, 0b00100000,
  0b10100111, 0b11010100, 0b11100000, 0b00100000,
  0b10001001, 0b01001001, 0b00010000, 0b01100000,
  0b11111010, 0b01000000, 0b00000000, 0b11110000,
  0b00010101, 0b11000000, 0b00000001, 0b10001100,
  0b00101010, 0b01000010, 0b00010001, 0b01000010,
  0b00100100, 0b11000010, 0b00010001, 0b01000010,
  0b00011100, 0b10010011, 0b11110101, 0b00100010,
  0b00000000, 0b11000100, 0b00001010, 0b00011100,
  0b00000000, 0b00111000, 0b00000110, 0b00000000,
  0b00000000, 0b00000000, 0b00000000, 0b00000000,
  0b00010000, 0b00000000, 0b00000000, 0b00000000,
  0b01101100, 0b00000000, 0b00000000, 0b00000000,
  0b00010000, 0b00000000, 0b00000000, 0b00000000
};

// HAPPY
const unsigned char PROGMEM petHappy[] = {
  0b00000000, 0b00010111, 0b11010000, 0b00001000,
  0b00000000, 0b00001000, 0b00100000, 0b00001000,
  0b00100000, 0b00000111, 0b11000000, 0b00010100,
  0b00100000, 0b00110000, 0b00110000, 0b01100011,
  0b01010000, 0b01001000, 0b01001000, 0b00010100,
  0b00100000, 0b01000100, 0b01001001, 0b11001000,
  0b00101110, 0b01000100, 0b10001010, 0b00101000,
  0b00010001, 0b01000011, 0b10000100, 0b00100000,
  0b00001000, 0b11000000, 0b00000101, 0b11000000,
  0b00001100, 0b11001100, 0b01100111, 0b00100000,
  0b00010011, 0b11010010, 0b10010100, 0b00100000,
  0b01010000, 0b10000000, 0b00000100, 0b11000010,
  0b10101000, 0b10000001, 0b00001011, 0b00100101,
  0b01001111, 0b10001000, 0b01010000, 0b11100010,
  0b00010000, 0b11100111, 0b10011111, 0b10000000,
  0b00001000, 0b00100011, 0b00000100, 0b11100000,
  0b00000111, 0b11100000, 0b00001100, 0b00111000,
  0b00000000, 0b00100100, 0b10001000, 0b00000100,
  0b00000000, 0b00100111, 0b10000111, 0b00000100,
  0b00000000, 0b00011000, 0b01100101, 0b10000100,
  0b00000000, 0b00000000, 0b00011100, 0b10001000,
  0b00000000, 0b01000000, 0b00000000, 0b01110000,
  0b00010000, 0b10100000, 0b00000000, 0b00000000,
  0b00010000, 0b01000000, 0b00000100, 0b00000000,
  0b00010000, 0b00000000, 0b00001010, 0b00000000,
  0b00101000, 0b00000000, 0b00000100, 0b00000000,
  0b11000110, 0b00000000, 0b00000000, 0b00000000,
  0b00101000, 0b00000000, 0b10000000, 0b00000000,
  0b00010000, 0b00000000, 0b10000000, 0b00000010,
  0b00010000, 0b00000001, 0b01000000, 0b00000101,
  0b00010000, 0b00000110, 0b00110000, 0b00000010,
  0b00000000, 0b00000001, 0b01000000, 0b00000000
};

// SLEEP
const unsigned char PROGMEM petSleep[] = {
  0b00000000, 0b00000000, 0b00000011, 0b11000000,
  0b01000000, 0b00000000, 0b01111000, 0b10000100,
  0b10100000, 0b01111100, 0b00010001, 0b00000100,
  0b01000001, 0b11000100, 0b00100011, 0b11000100,
  0b00000011, 0b00100100, 0b01111000, 0b00011011,
  0b00000110, 0b01001100, 0b00000000, 0b00000100,
  0b00001100, 0b10011001, 0b11100000, 0b00000100,
  0b00011001, 0b00110000, 0b01000000, 0b00000100,
  0b00010010, 0b01100000, 0b10000000, 0b00000000,
  0b00001000, 0b11000001, 0b11100000, 0b00000000,
  0b00001111, 0b10001100, 0b00000000, 0b00000000,
  0b11100000, 0b00010011, 0b11111110, 0b00000000,
  0b10010000, 0b00100010, 0b00000011, 0b10000000,
  0b01001000, 0b01000010, 0b00000000, 0b11000000,
  0b01001100, 0b01000010, 0b00011000, 0b01100000,
  0b01000111, 0b10000111, 0b00000111, 0b00110000,
  0b01100000, 0b00000100, 0b11110000, 0b10010000,
  0b01001100, 0b01100100, 0b00001110, 0b01010000,
  0b01000000, 0b00001000, 0b00000001, 0b11110000,
  0b01000000, 0b00001000, 0b00000000, 0b00001000,
  0b00100011, 0b00001000, 0b00001000, 0b00001000,
  0b00100001, 0b00010000, 0b00110000, 0b00001000,
  0b00100000, 0b00010000, 0b01100000, 0b00001000,
  0b00010000, 0b00100000, 0b11100000, 0b01001000,
  0b00101111, 0b11111111, 0b11100000, 0b10001000,
  0b00100011, 0b11110000, 0b00111111, 0b00001000,
  0b00100001, 0b10001101, 0b11100000, 0b00010000,
  0b01011000, 0b11000110, 0b00000000, 0b00100010,
  0b01000111, 0b10111101, 0b11111111, 0b11000010,
  0b10100000, 0b00000000, 0b00000000, 0b00000101,
  0b10111000, 0b00000000, 0b00000000, 0b00011101,
  0b01000000, 0b00000000, 0b00000000, 0b00000110
};

//***********************************************************
void drawBar(int x, int y, int value) {
  int maxBarWidth = 62; // Prevents clipping out the right boundary
  int barHeight = 5;    // Balanced text to spacing alignment
  int fillWidth = map(value, 0, 100, 0, maxBarWidth);

  display.drawRect(x, y, maxBarWidth, barHeight, SSD1306_WHITE);       // outline
  display.fillRect(x, y, fillWidth, barHeight, SSD1306_WHITE);        // filled portion
}

void render(){
  display.clearDisplay();
  const unsigned char* sprite;

  // Fixed: Validates sleep condition properly
  if (currentScreen == SCREEN_SLEEP) {
    sprite = petSleep;
  } else if (pet.hunger < 30 || pet.happiness < 30 || pet.energy < 30) {
    sprite = petSad;
  } else if (pet.hunger > 50 && pet.happiness > 50 && pet.energy > 50) {
    sprite = petHappy;
  } else {
    sprite = petNeutral;
  }

  // Refactored Layout: Pet rendered left (x=0) to make safe space for UI rows
  display.drawBitmap(0, 4, sprite, 32, 32, SSD1306_WHITE);
  display.setTextSize(1);

  // Status bars rendered at x=38 to remove any overlaps
  display.setCursor(38, 4);
  display.print("HUN");
  drawBar(62, 5, pet.hunger);

  display.setCursor(38, 14);
  display.print("HAP");
  drawBar(62, 15, pet.happiness);

  display.setCursor(38, 24);
  display.print("ENG");
  drawBar(62, 25, pet.energy);

  // Bottom action options adjusted perfectly within 128px screen wrap constraints
  int textWidth = 102;
  int x = (128 - textWidth) / 2;  // 13

  display.setCursor(13, 52);
  display.println("Feed  Play  Sleep");

  display.display();
}

void setup() {
  pinMode(BTN_LEFT, INPUT_PULLUP);
  pinMode(BTN_RIGHT, INPUT_PULLUP);
  pinMode(BTN_MIDDLE, INPUT_PULLUP); // Fixed: Missing trailing parenthesis added
  pinMode(BUZZER_PIN, OUTPUT);
  
  // Fixed: Hardware connection safety check loop
  if(!display.begin(SSD1306_SWITCHCAPVCC, 0x3C)) {
    while(true); // Dead halt if I2C display address is not acknowledging
  }
  
  display.clearDisplay();
  display.setTextSize(1);
  display.setTextColor(SSD1306_WHITE);
  display.setCursor(10, 24);
  display.println("Tamagotchi Init...");
  display.display();
  delay(1000);

  pet.hunger = 80;
  pet.happiness = 80;
  pet.energy = 80;
  pet.age = 0;
}

void loop() {
  checkButtons();       // 1. Read input
  updatePet();          // 2. Update state over time
  handleScreenLogic();  // 3. Process actions
  render();             // 4. Display results
  delay(100);           // 5. Short pause
}

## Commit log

2026-06-04 Add overview section for BibliGotchi project
    Added an overview section describing the BibliGotchi project and its features, including details about the custom PCB, OLED screen, battery, buttons, and case design.
2026-06-04 Enhance README with PCB design and firmware details
    Updated project description to include PCB design details and firmware information.
2026-06-04 Enhance PCB Gallery with additional views and routing
    Updated PCB Gallery section to include multiple views and added routing images.
2026-06-04 Enhance README with assembly tutorial and images
    Added detailed assembly steps and images for the case.
2026-06-04 Update image reference in assembly instructions
2026-06-05 Enhance firmware installation instructions in README
    Added detailed instructions for installing and flashing the firmware, including steps for setting up the ESP32 board in Arduino IDE.
2026-06-05 Add Bill of Materials and Build BOM sections to README
    Added a Bill of Materials (BOM) section with item details and a Build BOM section for assembly screws.
2026-06-05 Add schematic section with image to README
    Added schematic image section to README.
2026-06-05 Correct ESP32 model references in README
    Updated references from ESP32-C6 to ESP32-C3 in README.
2026-06-06 Revise BOM with new components and pricing
    Updated component details and prices, added shipping costs.
    [BOM.csv]
2026-06-06 Update BOM.csv with new item entries
    [BOM.csv]
2026-06-06 Fix formatting in BOM.csv
    Removed spaces before commas and fixed formatting issues.
    [BOM.csv]
2026-06-06 Revise component prices and BOM structure
    Updated pricing for ESP32-C3 MCU and separated PCB and shipping costs.
2026-06-06 Modify BOM.csv to add shipping item and fix format
    Updated BOM.csv to include a new shipping item and corrected formatting.
    [BOM.csv]
2026-06-07 Revise assembly tutorial for battery and PCB installation
    Updated assembly steps in the tutorial to reflect new battery installation process and PCB assembly.
2026-06-07 Fix image paths in README for assembly steps
    Updated image paths in assembly instructions for clarity.
2026-06-07 Update structural fasteners list in README
    Removed M2 Screws L16mm and updated total price calculations.
